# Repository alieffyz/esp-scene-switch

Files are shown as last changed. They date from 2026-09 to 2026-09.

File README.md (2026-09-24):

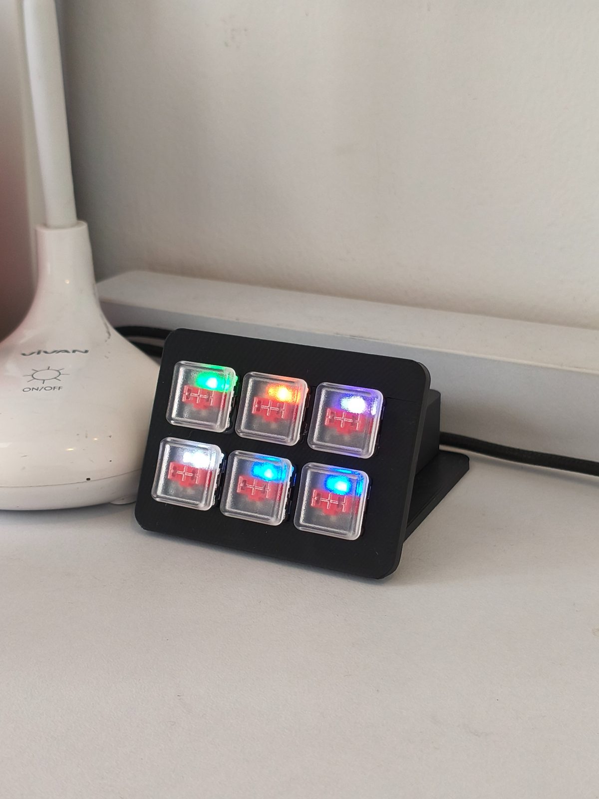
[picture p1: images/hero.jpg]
Scene Switch


# Scene Switch

A 6-button ESP32 scene controller with Kailh Choc switches and per-button WS2812B LED feedback, built for Home Assistant.

## Features

- 6 physical buttons, each with single/double/long-click detection
- Per-button addressable LED with color feedback (partitioned from a single LED strip)
- Soft white "click" pulse on every press for tactile feedback, independent of whatever effect/color is currently running
- Custom LED effects: Rainbow Flow, Meteor Flow, Knight Rider, Police Strobe, Color Wipe, Button Colors
- Boot LED sweep test on startup
- WiFi with primary + fallback SSID, plus local AP fallback if both fail
- Remembers and restores the last color/effect after a WiFi disconnect (shows an amber "breathing" indicator while disconnected)
- OTA updates with safe-mode rollback protection

## Setup

1. Copy `secrets_example.yaml` to `secrets.yaml` and fill in your own WiFi credentials, OTA password, and AP fallback password.
2. Generate a 32-byte base64 API encryption key using one of these terminal commands and add it to your `secrets.yaml`:
   - **Python**: `python -c "import secrets; import base64; print(base64.b64encode(secrets.token_bytes(32)).decode())"`
   - **PowerShell**: `$bytes = New-Object Byte[] 32; [Security.Cryptography.RNGCryptoServiceProvider]::Create().GetBytes($bytes); [Convert]::ToBase64String($bytes)`
3. Adjust GPIO pin assignments in `sceneswitch.yaml` if your wiring differs.
4. Flash via USB for the first install:
   ```bash
   esphome run sceneswitch.yaml
   ```
5. Subsequent updates can be done over OTA once the device is on your network.

## Optional Plugins

This project uses ESPHome's `packages:` feature to keep optional functionality in separate files instead of bloating `sceneswitch.yaml`. `packages:` can only *add* new globals, scripts, sensors, etc. — it can't patch existing list items (like an existing button's `on_multi_click:` block), so a plugin that needs to change existing button behavior still requires a small edit directly in `sceneswitch.yaml` (documented per-plugin below).

**Included Example Plugin (`plugins/media_mode.yaml`):**

Adds a "media mode" you can toggle by holding Button 4 (PC) + Button 6 together for ~450ms. While active, Buttons 4/5/6 send media-control events instead of their normal scene actions:

| Button | Single-click | Double-click | Long-press |
|---|---|---|---|
| 6 | Previous track | Volume down | — |
| 5 | Play/Pause | (unchanged, normal scene) | Mute |
| 4 | Next track | Volume up | — |

Entering/exiting mode gives a green double-blink confirmation, then the three LEDs stay a dim cyan while active. Two entities are also exposed to Home Assistant: `binary_sensor.scene_switch_media_mode` (on/off) and `text_sensor.scene_switch_current_mode` ("Scene" / "Media").

Requires [HASS.Agent](https://github.com/HASS-Agent/HASS.Agent) (or similar) installed on your Windows PC, exposed to HA as a `media_player` entity, plus a Home Assistant automation listening for the `esphome.scene_switch_media` event (see below) to actually route the commands to it.

**How it's wired in (already done for this plugin, shown here as a reference for writing your own):**

1. `sceneswitch.yaml` loads it via `packages:` at the top of the file:
   ```yaml
   packages:
     media_mode: !include plugins/media_mode.yaml
   ```
   Packages are always active once included — there's no toggle/uncomment step.
2. Buttons 4, 5, and 6's `on_multi_click:` blocks in `sceneswitch.yaml` each check `media_mode` (a global defined in the plugin) and branch between firing the normal `esphome.scene_switch_button` event or the plugin's `esphome.scene_switch_media` event.

To add your own plugin: create a new file under `plugins/`, add it to the `packages:` map the same way, and if it needs to change existing button behavior, edit that button's block in `sceneswitch.yaml` directly.

## Home Assistant Automation Mapping

The firmware fires Home Assistant events for each button press. Because workflows vary, **button actions are not hardcoded in ESPHome**. You must create Home Assistant automations triggered by these events.

**Example Automation — scene buttons (`esphome.scene_switch_button`):**
```yaml
alias: Scene Switch - Spotlight Gestures
triggers:
  - event_type: esphome.scene_switch_button
    event_data:
      button: spotlight
      click_type: single
    trigger: event
  - event_type: esphome.scene_switch_button
    event_data:
      button: spotlight
      click_type: double
    trigger: event
  - event_type: esphome.scene_switch_button
    event_data:
      button: spotlight
      click_type: long
    trigger: event
actions:
  - choose:
      - conditions:
          - condition: template
            value_template: "{{ trigger.event.data.click_type == 'single' }}"
        sequence:
          - action: switch.toggle
            target:
              entity_id: switch.spotlight_kamar_alief
      - conditions:
          - condition: template
            value_template: "{{ trigger.event.data.click_type == 'double' }}"
        sequence:
          - action: light.turn_off
            target:
              entity_id:
                - light.bawah_1
                - light.bawah_2
                - light.kasur_1
                - light.kasur_2
                - light.tangga_1
                - light.tangga_2
      - conditions:
          - condition: template
            value_template: "{{ trigger.event.data.click_type == 'long' }}"
        sequence:
          - action: script.turn_on
            target:
              entity_id: script.all_lights_smart_toggle
```

**Example Automation — media mode (`esphome.scene_switch_media`, only needed if you enable the `media_mode` plugin):**
```yaml
alias: Scene Switch - Media Control
trigger:
  - platform: event
    event_type: esphome.scene_switch_media
action:
  - choose:
      - conditions: "{{ trigger.event.data.action == 'next' }}"
        sequence:
          - service: media_player.media_next_track
            target:
              entity_id: media_player.your_pc_here
      - conditions: "{{ trigger.event.data.action == 'prev' }}"
        sequence:
          - service: media_player.media_previous_track
            target:
              entity_id: media_player.your_pc_here
      - conditions: "{{ trigger.event.data.action == 'volume_up' }}"
        sequence:
          - service: media_player.volume_up
            target:
              entity_id: media_player.your_pc_here
      - conditions: "{{ trigger.event.data.action == 'volume_down' }}"
        sequence:
          - service: media_player.volume_down
            target:
              entity_id: media_player.your_pc_here
      - conditions: "{{ trigger.event.data.action == 'play_pause' }}"
        sequence:
          - service: media_player.media_play_pause
            target:
              entity_id: media_player.your_pc_here
      - conditions: "{{ trigger.event.data.action == 'mute' }}"
        sequence:
          - service: media_player.volume_mute
            target:
              entity_id: media_player.your_pc_here
            data:
              is_volume_muted: true
mode: single
```

## Hardware

- ESP32 (any variant with enough GPIOs for 6 buttons + 1 LED data pin). Tested on a generic ESP32 DevKit V1 (`board: esp32dev` in the config, Arduino framework). Should work on any classic ESP32 (not S2/S3/C3) dev board with the same GPIO layout — if you're on a different chip variant, update `board:` under the `esp32:` block and double-check your GPIO assignments, since pin availability differs across variants.
- 6x Kailh Choc V1 switches
- 6x WS2812B addressable LEDs (one per button)
- Custom 3D-printed enclosure (FDM) — CAD files in [`cad/`](./cad).

## CAD Files

STEP files for the enclosure are in `cad/`:
- `Cover.step` — back cover
- `Faceplate.step` — front faceplate

This is v1 — fit and finish aren't perfect yet, see Known Issues below.

## Known Issues / v2 TODO

- Enclosure fit tolerances are a bit tight/loose in places, needs dialing in.
- Back cover was originally too close to the ESP32 (1-2mm gap), caused thermal buildup — fixed in software by switching WiFi `power_save_mode` to `light`, but v2 needs proper ventilation holes in the CAD design.
- **Stop Hand-Soldering**: WS2812B LEDs had to be cut apart individually and hand-soldered with very fine wire. DIN of LED1 ended up wired to what's physically Button 6, requiring software mapping fixes. **v2 MUST use a custom printed PCB (e.g., from JLCPCB).** It's significantly cheaper in time/effort, makes the build 10x more rigid, and ensures correct LED data routing without software hacks.

## Firmware Gotchas / Lessons Learned

- **Custom LED effects going completely dark**: effects that called `current_values_as_rgb()` on the light from inside their own effect update (Meteor Flow, Knight Rider, Scanner, Solder Chase) would render nothing at all. Fixed by reading the last-known color from stored `prev_red`/`prev_green`/`prev_blue` globals instead of querying the light's own live state mid-effect.
- **LED flash scripts doing nothing visible**: using a raw C++ `delay()` inside a single lambda (between two `schedule_show()` calls) never actually pushes pixel data to the strip — `schedule_show()` just flags "dirty," and the real hardware write only happens when control returns to ESPHome's scheduler. A blocking `delay()` never yields that control back, so the flash gets computed and immediately overwritten before it's ever shown. Fixed by using real ESPHome `delay:` script steps (which do yield) instead of blocking C++ calls.
- **WiFi-reconnect state getting stuck on the disconnect indicator (amber breathing)**: two separate causes — (1) the "previous state" globals were saved with `restore_value: true`, so a corrupted value from early testing got permanently written to flash and kept surviving reflashes; and (2) the light's generic `on_state` handler saved "previous state" on *every* state change, including the disconnect indicator's own color changes, overwriting the real saved state moments after it was captured. Fixed by setting `restore_value: false` on those globals and adding a guard so state is never saved while the disconnect indicator itself is active.
- **WiFi fallback SSID never triggering**: pinning a `bssid:` on the primary network entry prevents fallback to a second SSID entirely if that specific access point becomes unreachable, since the device won't roam off a pinned BSSID. Removed the pin so both SSIDs can be tried freely, with `priority:` used to prefer one over the other.

## Notes

- `power_save_mode: light` is used to reduce WiFi radio heat/idle temperature — set to `none` only if you need lower API latency and don't mind the extra heat.
- The LED-to-button physical mapping may need adjusting (`from:`/`to:` under the `partition` platform lights) depending on your specific wiring order.

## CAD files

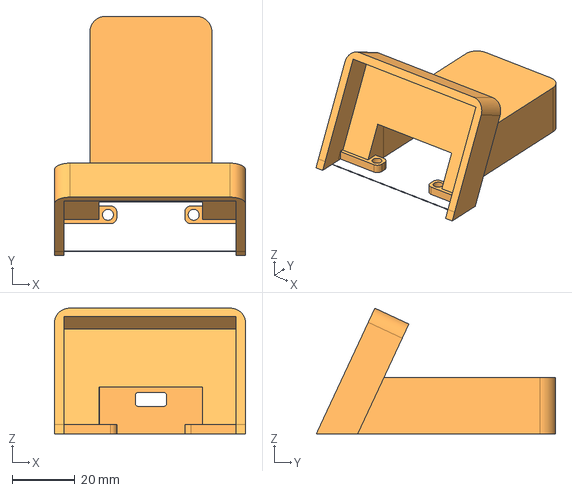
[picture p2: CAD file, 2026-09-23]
cad/Cover.step
61.0 x 76.5 x 40.1 mm

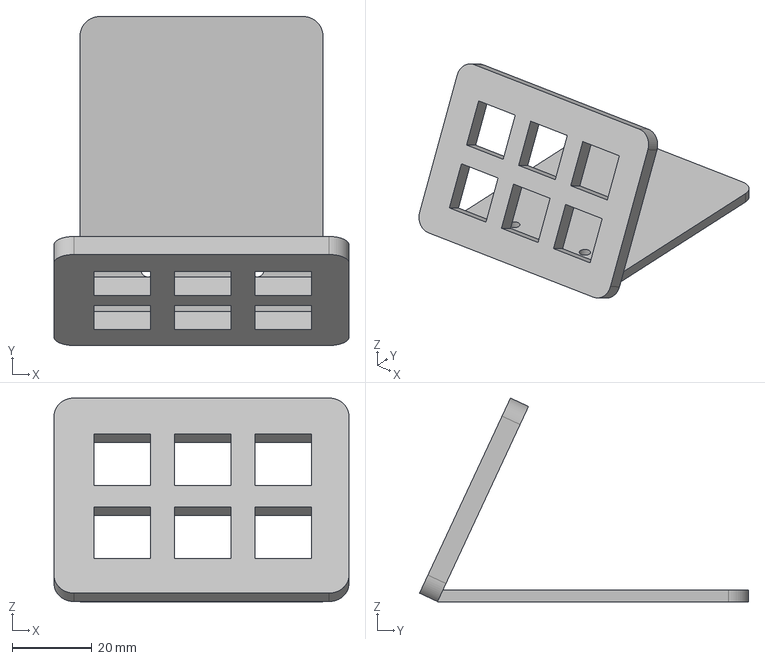
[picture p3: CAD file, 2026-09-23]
cad/Faceplate.step
74.0 x 82.5 x 51.2 mm

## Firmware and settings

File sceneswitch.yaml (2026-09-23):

esphome:
  name: scene-switch
  friendly_name: Scene Switch
  on_boot:
    priority: 600
    then:
      - text_sensor.template.publish:
          id: button1_state
          state: "-"
      - text_sensor.template.publish:
          id: button2_state
          state: "-"
      - text_sensor.template.publish:
          id: button3_state
          state: "-"
      - text_sensor.template.publish:
          id: button4_state
          state: "-"
      - text_sensor.template.publish:
          id: button5_state
          state: "-"
      - text_sensor.template.publish:
          id: button6_state
          state: "-"
      # Jalankan test sweep LED secara penuh dulu sampai beres saat boot
      - script.execute: led_test_sweep

script:
  # Soft white pulse pas tombol dipencet - ga peduli efek/warna apa yang lagi jalan
  - id: click_flash_script
    parameters:
      led_index: int
    then:
      - lambda: |-
          auto *leds = (light::AddressableLight *) id(led_strip).get_output();
          if (led_index < 0 || led_index >= (int) leds->size()) return;
          Color prev = (*leds)[led_index].get();
          id(flash_prev_r) = prev.r;
          id(flash_prev_g) = prev.g;
          id(flash_prev_b) = prev.b;
          (*leds)[led_index] = Color(25, 25, 25);
          leds->schedule_show();
      - delay: 80ms
      - lambda: |-
          auto *leds = (light::AddressableLight *) id(led_strip).get_output();
          if (led_index < 0 || led_index >= (int) leds->size()) return;
          (*leds)[led_index] = Color(57, 57, 57);
          leds->schedule_show();
      - delay: 80ms
      - lambda: |-
          auto *leds = (light::AddressableLight *) id(led_strip).get_output();
          if (led_index < 0 || led_index >= (int) leds->size()) return;
          (*leds)[led_index] = Color(89, 89, 89);
          leds->schedule_show();
      - delay: 100ms
      - lambda: |-
          auto *leds = (light::AddressableLight *) id(led_strip).get_output();
          if (led_index < 0 || led_index >= (int) leds->size()) return;
          (*leds)[led_index] = Color(57, 57, 57);
          leds->schedule_show();
      - delay: 80ms
      - lambda: |-
          auto *leds = (light::AddressableLight *) id(led_strip).get_output();
          if (led_index < 0 || led_index >= (int) leds->size()) return;
          (*leds)[led_index] = Color(25, 25, 25);
          leds->schedule_show();
      - delay: 80ms
      - lambda: |-
          auto *leds = (light::AddressableLight *) id(led_strip).get_output();
          if (led_index < 0 || led_index >= (int) leds->size()) return;
          (*leds)[led_index] = Color(id(flash_prev_r), id(flash_prev_g), id(flash_prev_b));
          leds->schedule_show();

  - id: led_test_sweep
    then:
      - light.turn_off: led_strip
      - light.turn_on:
          id: led_spotlight
          red: 100%
          green: 0%
          blue: 0%
          brightness: 80%
      - delay: 400ms
      - light.turn_on:
          id: led_spotlight
          red: 0%
          green: 100%
          blue: 0%
      - delay: 400ms
      - light.turn_on:
          id: led_spotlight
          red: 0%
          green: 0%
          blue: 100%
      - delay: 400ms
      - light.turn_off: led_spotlight

      - light.turn_on:
          id: led_fan
          red: 100%
          green: 0%
          blue: 0%
          brightness: 80%
      - delay: 400ms
      - light.turn_on:
          id: led_fan
          red: 0%
          green: 100%
          blue: 0%
      - delay: 400ms
      - light.turn_on:
          id: led_fan
          red: 0%
          green: 0%
          blue: 100%
      - delay: 400ms
      - light.turn_off: led_fan

      - light.turn_on:
          id: led_ac
          red: 100%
          green: 0%
          blue: 0%
          brightness: 80%
      - delay: 400ms
      - light.turn_on:
          id: led_ac
          red: 0%
          green: 100%
          blue: 0%
      - delay: 400ms
      - light.turn_on:
          id: led_ac
          red: 0%
          green: 0%
          blue: 100%
      - delay: 400ms
      - light.turn_off: led_ac

      - light.turn_on:
          id: led_pc
          red: 100%
          green: 0%
          blue: 0%
          brightness: 80%
      - delay: 400ms
      - light.turn_on:
          id: led_pc
          red: 0%
          green: 100%
          blue: 0%
      - delay: 400ms
      - light.turn_on:
          id: led_pc
          red: 0%
          green: 0%
          blue: 100%
      - delay: 400ms
      - light.turn_off: led_pc

      - light.turn_on:
          id: led_scene5
          red: 100%
          green: 0%
          blue: 0%
          brightness: 80%
      - delay: 400ms
      - light.turn_on:
          id: led_scene5
          red: 0%
          green: 100%
          blue: 0%
      - delay: 400ms
      - light.turn_on:
          id: led_scene5
          red: 0%
          green: 0%
          blue: 100%
      - delay: 400ms
      - light.turn_off: led_scene5
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

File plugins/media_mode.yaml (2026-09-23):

# Media Mode "plugin" - hold Button 4 (PC) + Button 6 together for ~450ms
# to toggle Spotify/PC media control mode on buttons 4 & 6.
# The actual on_multi_click branching for buttons 4/6 still lives in
# sceneswitch.yaml itself (ESPHome packages can't patch existing list items).

globals:
  - id: media_mode
    type: bool
    restore_value: false
    initial_value: "false"
  - id: chord_active
    type: bool
    restore_value: false
    initial_value: "false"
  - id: chord_consumed
    type: bool
    restore_value: false
    initial_value: "false"
  - id: chord_hold_start
    type: uint32_t
    restore_value: false
    initial_value: "0"
  # Saved *pre-brightness* colors for PC LED (index 2) and scene6 LED (index 0).
  # Stored un-scaled (0-255 raw) so we can re-scale to whatever HA brightness
  # is at restore time.
  - id: media_prev_pc_r
    type: uint8_t
    restore_value: false
    initial_value: "255"
  - id: media_prev_pc_g
    type: uint8_t
    restore_value: false
    initial_value: "255"
  - id: media_prev_pc_b
    type: uint8_t
    restore_value: false
    initial_value: "255"
  - id: media_prev_scene6_r
    type: uint8_t
    restore_value: false
    initial_value: "255"
  - id: media_prev_scene6_g
    type: uint8_t
    restore_value: false
    initial_value: "255"
  - id: media_prev_scene6_b
    type: uint8_t
    restore_value: false
    initial_value: "255"
  - id: media_prev_brightness
    type: float
    restore_value: false
    initial_value: "1.0"

interval:
  # Chord detector: PC + scene6 held together for 450ms toggles media mode
  - interval: 50ms
    then:
      - lambda: |-
          bool both_held = id(button_pc).state && id(button_scene6).state;
          if (both_held) {
            if (!id(chord_active)) {
              id(chord_active) = true;
              id(chord_hold_start) = millis();
            } else if (!id(chord_consumed) && (millis() - id(chord_hold_start) >= 450)) {
              id(chord_consumed) = true;
              id(media_mode) = !id(media_mode);
              id(media_mode_confirm_script).execute();
            }
          } else {
            id(chord_active) = false;
            id(chord_consumed) = false;
          }

  # Live brightness tracking: while media mode is active, keep the cyan
  # LEDs on PC + scene6 synced to whatever HA master brightness currently is.
  - interval: 100ms
    then:
      - lambda: |-
          if (!id(media_mode)) return;
          if (!id(boot_sweep_completed)) return;
          auto *leds = (light::AddressableLight *) id(led_strip).get_output();
          float b = id(led_strip).remote_values.get_brightness();
          // Only redraw if color actually differs to avoid hammering the strip
          Color cyan = Color(0, (uint8_t)(200 * b), (uint8_t)(255 * b));
          Color cur_pc = (*leds)[2].get();
          Color cur_s6 = (*leds)[0].get();
          if (cur_pc.r != cyan.r || cur_pc.g != cyan.g || cur_pc.b != cyan.b ||
              cur_s6.r != cyan.r || cur_s6.g != cyan.g || cur_s6.b != cyan.b) {
            (*leds)[2] = cyan;
            (*leds)[0] = cyan;
            leds->schedule_show();
          }

script:
  - id: media_mode_confirm_script
    then:
      - lambda: |-
          auto *leds = (light::AddressableLight *) id(led_strip).get_output();
          float b = id(led_strip).remote_values.get_brightness();
          if (b < 0.01f) b = 0.01f;  // avoid div-by-zero on save

          if (id(media_mode)) {
            // Entering media mode: save *un-scaled* colors so we can
            // re-apply at whatever brightness HA has at restore time.
            float inv = 1.0f / b;
            Color pc = (*leds)[2].get();
            Color s6 = (*leds)[0].get();
            float r;
            r = pc.r * inv; id(media_prev_pc_r)     = (uint8_t)(r > 255.0f ? 255.0f : r);
            r = pc.g * inv; id(media_prev_pc_g)     = (uint8_t)(r > 255.0f ? 255.0f : r);
            r = pc.b * inv; id(media_prev_pc_b)     = (uint8_t)(r > 255.0f ? 255.0f : r);
            r = s6.r * inv; id(media_prev_scene6_r) = (uint8_t)(r > 255.0f ? 255.0f : r);
            r = s6.g * inv; id(media_prev_scene6_g) = (uint8_t)(r > 255.0f ? 255.0f : r);
            r = s6.b * inv; id(media_prev_scene6_b) = (uint8_t)(r > 255.0f ? 255.0f : r);
            id(media_prev_brightness) = b;
          }

          // Blink 1: green at current brightness
          Color green = Color(0, (uint8_t)(255 * b), 0);
          (*leds)[2] = green;
          (*leds)[0] = green;
          leds->schedule_show();

      - delay: 150ms

      - lambda: |-
          auto *leds = (light::AddressableLight *) id(led_strip).get_output();
          (*leds)[2] = Color(0, 0, 0);
          (*leds)[0] = Color(0, 0, 0);
          leds->schedule_show();

      - delay: 150ms
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
